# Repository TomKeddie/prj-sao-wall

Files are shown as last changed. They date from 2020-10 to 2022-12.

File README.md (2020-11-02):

# prj-sao-wall

## Nov2020 Errata
- Untested

## Sep2020 Errata
- add jtag pins
- SPI header has rows swapped and wierd footprint
- Connectors on either end are too close to the edge
- xtal footprint is wrong (need 4 pin)
- C8 move to Y centre to narrow slot width
- X3 change to power pwm
- change to 500mA pnp transistors in place of n-fets
- change to 4x2 connectors on either end

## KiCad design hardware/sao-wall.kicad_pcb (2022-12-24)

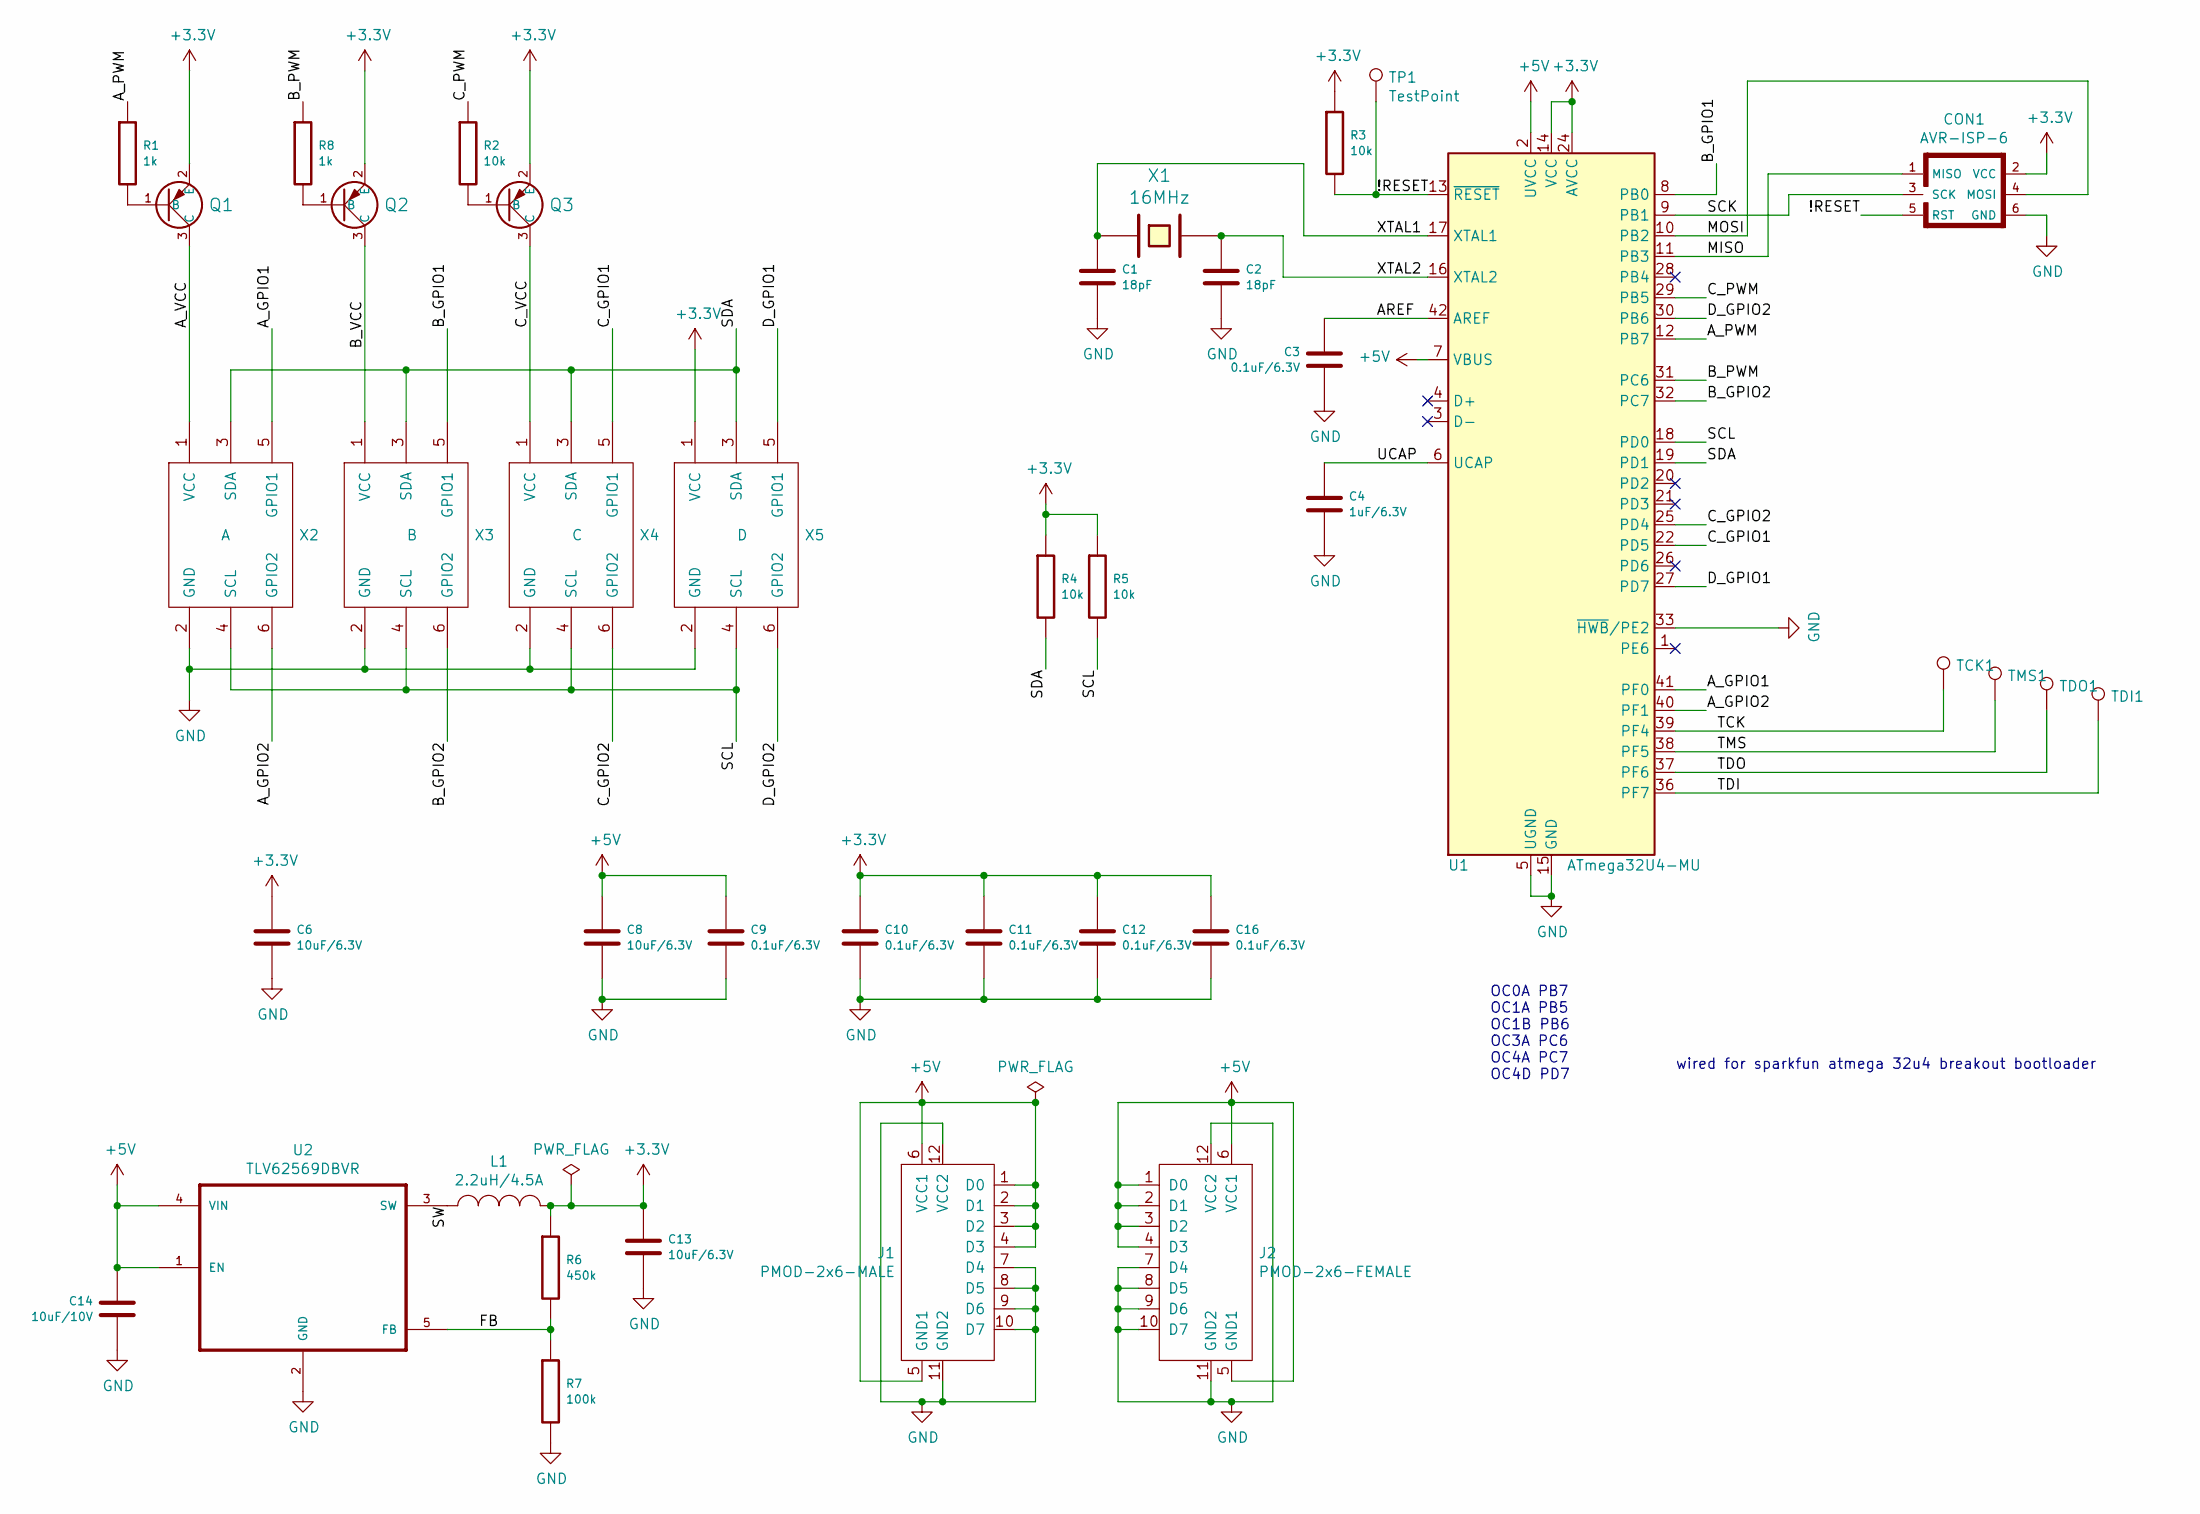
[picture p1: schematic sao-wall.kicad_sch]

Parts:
C1, C2: 18pF; C_0805_2012Metric
C3, C9, C10, C11, C12, C16: 0.1uF/6.3V; C_0805_2012Metric
C4: 1uF/6.3V; C_0805_2012Metric
C6, C8, C13: 10uF/6.3V; C_0805_2012Metric
C14: 10uF/10V; C_0805_2012Metric
CON1: AVR-ISP-6; PinTestpoint_2x03_P2.54mm_Vertical
J1: PMOD-2x6-MALE; 2X6_SMD_RA_PLUG
J2: PMOD-2x6-FEMALE; 2X6_SMD_RA_SOCKET
L1: 2.2uH/4.5A; L_MWSA0518S
Q1, Q2, Q3: PMBT2907A_PNP_500mA; SOT23_NXP
R1, R8: 1k; R_0805_2012Metric
R2, R3, R4, R5: 10k; R_0805_2012Metric
R6: 450k; R_0805_2012Metric
R7: 100k; R_0805_2012Metric
TCK1: TCK; TestPoint_Pad_D1.5mm
TDI1: TDI; TestPoint_Pad_D1.5mm
TDO1: TDO; TestPoint_Pad_D1.5mm
TMS1: TMS; TestPoint_Pad_D1.5mm
TP1: TestPoint; TestPoint_Pad_D1.5mm
U1: ATmega32U4-MU; TQFP-44_10x10mm_P0.8mm
U2: TLV62569DBVR; SOT-23-5; LCSC C141836
X1: 16MHz; Crystal_SMD_5032-2Pin_5.0x3.2mm; MPN CX5032GB16
X2: A; Badgelife-SAOv169-SAO-2x3
X3: B; Badgelife-SAOv169-SAO-2x3
X4: C; Badgelife-SAOv169-SAO-2x3
X5: D; Badgelife-SAOv169-SAO-2x3

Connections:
+3.3V: C6.1, C10.1, C11.1, C12.1, C13.1, C16.1, CON1.2 (VCC), L1.2, Q1.2 (E), Q2.2 (E), Q3.2 (E), R3.1, R4.1, R5.1, R6.1, U1.14 (VCC), U1.24 (AVCC), U1.34 (VCC), U1.44 (AVCC), X5.1 (VCC)
+5V: C8.1, C9.1, C14.2, J1.1 (D0), J1.2 (D1), J1.3 (D2), J1.4 (D3), J1.5 (GND1), J1.6 (VCC1), J2.1 (D0), J2.2 (D1), J2.3 (D2), J2.4 (D3), J2.5 (GND1), J2.6 (VCC1), U1.2 (UVCC), U1.7 (VBUS), U2.1 (EN), U2.4 (VIN)
/!RESET: CON1.5 (RST), R3.2, TP1.1, U1.13 (~RESET)
/AREF: C3.2, U1.42 (AREF)
/A_GPIO1: U1.41 (PF0), X2.5 (GPIO1)
/A_GPIO2: U1.40 (PF1), X2.6 (GPIO2)
/A_PWM: R1.1, U1.12 (PB7)
/A_VCC: Q1.3 (C), X2.1 (VCC)
/B_GPIO1: U1.8 (PB0), X3.5 (GPIO1)
/B_GPIO2: U1.32 (PC7), X3.6 (GPIO2)
/B_PWM: R8.1, U1.31 (PC6)
/B_VCC: Q2.3 (C), X3.1 (VCC)
/C_GPIO1: U1.22 (PD5), X4.5 (GPIO1)
/C_GPIO2: U1.25 (PD4), X4.6 (GPIO2)
/C_PWM: R2.1, U1.29 (PB5)
/C_VCC: Q3.3 (C), X4.1 (VCC)
/D_GPIO1: U1.27 (PD7), X5.5 (GPIO1)
/D_GPIO2: U1.30 (PB6), X5.6 (GPIO2)
/FB: R6.2, R7.1, U2.5 (FB)
/MISO: CON1.1 (MISO), U1.11 (PB3)
/MOSI: CON1.4 (MOSI), U1.10 (PB2)
/SCK: CON1.3 (SCK), U1.9 (PB1)
/SCL: R5.2, U1.18 (PD0), X2.4 (SCL), X3.4 (SCL), X4.4 (SCL), X5.4 (SCL)
/SDA: R4.2, U1.19 (PD1), X2.3 (SDA), X3.3 (SDA), X4.3 (SDA), X5.3 (SDA)
/SW: L1.1, U2.3 (SW)
/TCK: TCK1.1, U1.39 (PF4)
/TDI: TDI1.1, U1.36 (PF7)
/TDO: TDO1.1, U1.37 (PF6)
/TMS: TMS1.1, U1.38 (PF5)
/UCAP: C4.1, U1.6 (UCAP)
/XTAL1: C1.1, U1.17 (XTAL1), X1.1
/XTAL2: C2.1, U1.16 (XTAL2), X1.2
GND: C1.2, C2.2, C3.1, C4.2, C6.2, C8.2, C9.2, C10.2, C11.2, C12.2, C13.2, C14.1, C16.2, CON1.6 (GND), J1.7 (D4), J1.8 (D5), J1.9 (D6), J1.10 (D7), J1.11 (GND2), J1.12 (VCC2), J2.7 (D4), J2.8 (D5), J2.9 (D6), J2.10 (D7), J2.11 (GND2), J2.12 (VCC2), R7.2, U1.5 (UGND), U1.15 (GND), U1.23 (GND), U1.33 (~HWB/PE2), U1.35 (GND), U1.43 (GND), U1.45 (GND), U2.2 (GND), X2.2 (GND), X3.2 (GND), X4.2 (GND), X5.2 (GND)
unnamed: Q1.1 (B), R1.2
unnamed: Q2.1 (B), R8.2
unnamed: Q3.1 (B), R2.2

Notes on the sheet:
wired for sparkfun atmega 32u4 breakout bootloader
OC0A PB7 OC1A PB5 OC1B PB6 OC3A PC6 OC4A PC7 OC4D PD7

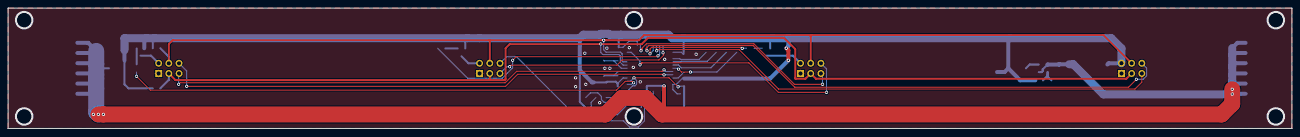
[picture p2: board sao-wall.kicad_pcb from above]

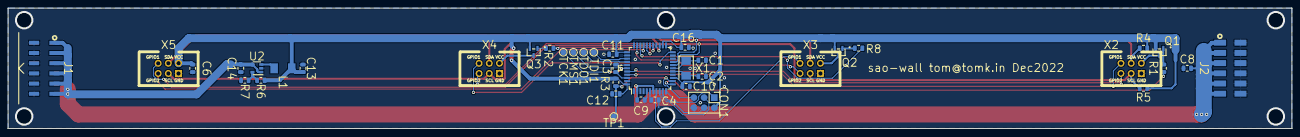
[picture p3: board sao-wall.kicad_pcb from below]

Board: 2 copper layers, 320.0 x 30.0 mm, 40 parts (36 on the bottom side), 36 nets.

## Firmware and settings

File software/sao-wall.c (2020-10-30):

#include <stdlib.h>
#include <avr/io.h>
#include <avr/interrupt.h>

// Pins
// A_PWM   OC0A PB7 (Arduino D11)
// B_PWM   OC3A PC6 (Arduino D5)
// C_PWM   OC1A PB5 (Arduino D9)
// D_GPIO2 OC1B PB6 (Arduino D10)
// D_GPIO1 OC4D PD7 (Arduino D6)

#define A_GPIO1 PF0
#define A_GPIO2 PF1
#define C_GPIO1 PF4
#define C_GPIO2 PF5

static volatile uint8_t m_level0 = 4+0*256/5;
static volatile uint8_t m_level1 = 4+1*256/5;
static volatile uint8_t m_level2 = 4+2*256/5;
static volatile uint8_t m_level3 = 4+3*256/5;
static volatile uint8_t m_level4 = 4+4*256/5;


static void update_ocr(void) {
    OCR0A = m_level0;
    OCR3A = m_level1;
    OCR1A = m_level2;
    OCR1B = m_level3;
    OCR4D = m_level4;
}    

void main(void) {
    DDRB = (1 << DDB5) | (1 << DDB6) | (1 << DDB7);
    DDRC = (1 << DDC6);
    DDRD = (1 << DDD7) | (1 << DDD1);
    DDRF = (1 << DDF5) | (1 << DDF4) | (1 << DDF1) | (1 << DDF0);

    // use timer 0 to drive the level change logic
    TIFR0  = 0;
    TIMSK0 = (1 << TOIE0);
    
    TCCR0A = (1 << WGM00) | (1 << COM0A0) | (1 << COM0A1); // 8 bit, non inverting on A
    TCCR0B = (1 << CS02); // Set up timer as /256 (16000000 / 256) = 62500 Hz / 512 = 122 Hz
    TCCR1A = (1 << WGM10) | (1 << COM1A1) | (1 << COM1A0) | (1 << COM1B1) | (1 << COM1B0); // 8 bit, non-inverting on A and B
    TCCR1B = (1 << CS12); // Set up timer as /256 (16000000 / 256) = 62500 Hz / 512 = 122 Hz
    TCCR3A = (1 << WGM30) | (1 << COM3A0) | (1 << COM3A1); // 8 bit, non inverting on A
    TCCR3B = (1 << CS32); // Set up timer as /256 (16000000 / 256) = 62500 Hz / 512 = 122 Hz
    TCCR4A = (1 << PWM4A) | (1 << COM4A0) | (1 << COM4A1); // 8 bit, non inverting on A
    TCCR4B = (1 << CS43) | (1 << CS40); // Set up timer as /256 (16000000 / 256) = 62500 Hz / 512 = 122 Hz
    TCCR4C = (1 << COM4A1S) | (1 << COM4A0S) | (1 << PWM4D) | (1 << COM4D0) | (1 << COM4D1); // 8 bit, non inverting on D
    TCCR4D = (1 << WGM40); // phase/freq correct

    sei();

    PORTF |= 1;
    PORTF &= !1;

    PORTF |= 1;
    PORTF &= !1;

    update_ocr();

    while(1) {} ;
}

ISR(TIMER0_OVF_vect) {
    static uint8_t counter = 0;
    static uint8_t increment0 = 1;
    static uint8_t increment1 = 1;
    static uint8_t increment2 = 1;
    static uint8_t increment3 = 1;
    static uint8_t increment4 = 1;
    if (++counter == 8) {
        counter = 0;
        if (increment0) m_level0++; else m_level0--;
        if (increment1) m_level1++; else m_level1--;
        if (increment2) m_level2++; else m_level2--;
        if (increment3) m_level3++; else m_level3--;
        if (increment4) m_level4++; else m_level4--;
        if (m_level0 == 0xff) increment0 = 0; if (m_level0 == 4) increment0 = 1;
        if (m_level1 == 0xff) increment1 = 0; if (m_level1 == 4) increment1 = 1;
        if (m_level2 == 0xff) increment2 = 0; if (m_level2 == 4) increment2 = 1;
        if (m_level3 == 0xff) increment3 = 0; if (m_level3 == 4) increment3 = 1;
        if (m_level4 == 0xff) increment4 = 0; if (m_level4 == 4) increment4 = 1;
        update_ocr();
    }
}

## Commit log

2020-09-29 sao-wall : as sent to jlcpcb Sep 2020
    [sao-wall-B_Cu.gbr, sao-wall-B_Mask.gbr, sao-wall-B_Paste.gbr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]
2020-10-07 software: OC0A, OC1A and OC1B working at 122Hz
2020-10-07 software: config for all 6 pwm channels, OC4A seems not to be working
2020-10-09 Software: All 6 channels of pwm working at different rates, added COM4A1S & COM4A0S
2020-10-10 Getting pcb design ready to move to separate repo
    [sao-wall-B_Cu.gbr, sao-wall-B_Mask.gbr, sao-wall-B_Paste.gbr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]
2020-10-10 Added pcb files from prj-pcb-experiments
    [sao-wall-B_Cu.gbr, sao-wall-B_Mask.gbr, sao-wall-B_Paste.gbr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]
2020-11-02 hardware: Nov2020 version of pcb with errata fixed
    [sao-wall-B_Cu.gbr, sao-wall-B_Mask.gbr, sao-wall-B_Paste.gbr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]
2022-12-23 hardware: update files to kicad 6
    [sao-wall.kicad_sch]
2022-12-24 hardware: move to QFP cpu package, Dec2022 release
    [sao-wall-B_Cu.gbl, sao-wall-B_Cu.gbr, sao-wall-B_Mask.gbr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]

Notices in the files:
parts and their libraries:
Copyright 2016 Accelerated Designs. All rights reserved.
